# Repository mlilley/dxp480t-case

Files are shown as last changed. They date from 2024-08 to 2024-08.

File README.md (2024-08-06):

# DXP480T Custom Case

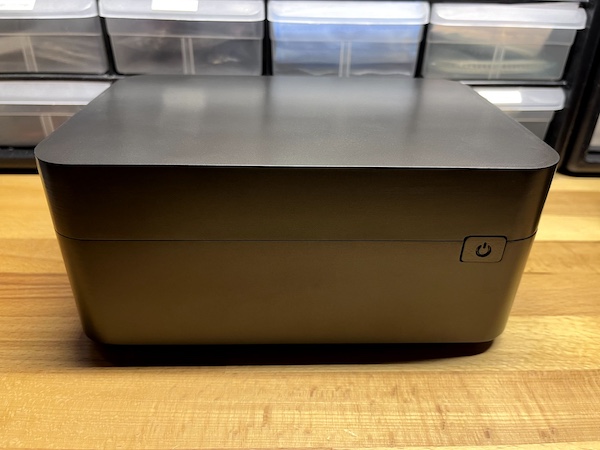
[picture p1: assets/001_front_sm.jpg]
Front


For more pictures, see: https://photos.app.goo.gl/Rahk7zdu8heuZMXZ9

## Printing & Assembly

Recommend printing case parts in ASA (to resist the hardware's high temps).  PLA or PETG should be avoided and will melt and/or distort.

To assemble ASA parts, prepare a mix of acetone and ASA scraps to make a glue.

You will also need:
* 20 x 5x2mm neodynium magnets (for the fan cover)
* 8 x M3 brass inserts (for the case halves and fan mount)
* 4 x 25mm M3 bolts (for case halves)
* 4 x 8mm M3 bolts (for fan)
* 1 x Noctua 120x25mm PWM fan (or compatible alternative)
* 1 x Noctua NA-FC1 PWM fan controller (or compatible alternative)
* 2 x 120x120mm pvc fan grille (or suitable alternative)

## NVME Mounting Bracket

To secure the NVME drives, see this repo for a 3d printable mounting bracket:
[dxp480t-nvme-bracket](https://github.com/mlilley/dxp480t-nvme-bracket)

## Fan Power

12V and ground for the 120mm fan can be obtained from the motherboard's pogo pin pads that originally connected to the factory case's uderside fans.

## Painting

To paint, I recommend spraying with a suitable primer before top coating with your chosen top coat.  I used [Mr. Finishing Surfacer 1500 Black](https://www.mr-hobby.com/en/product2/category_33/256.html) to prime, then [Gun Metal](https://www.splash-paints.com/product-page/gunmetal) from [Barbatos Rex' Mecha Empire range](https://www.splash-paints.com/barbatosrex) of anodized-look lacquers from Splash Paints.

I used an airbrush with a 0.8mm needle to get reasonable coverage over the large case parts.

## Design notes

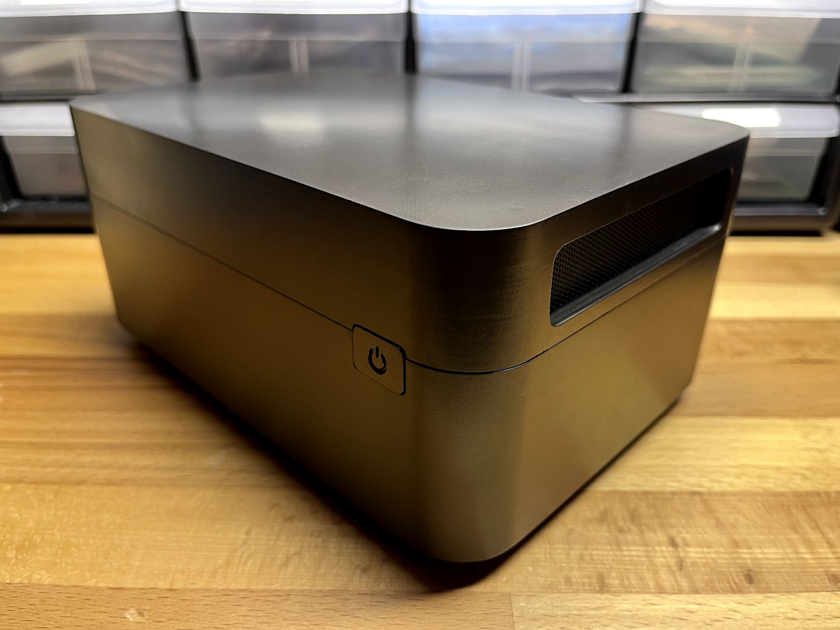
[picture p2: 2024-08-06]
assets/003_frontcorner.jpg

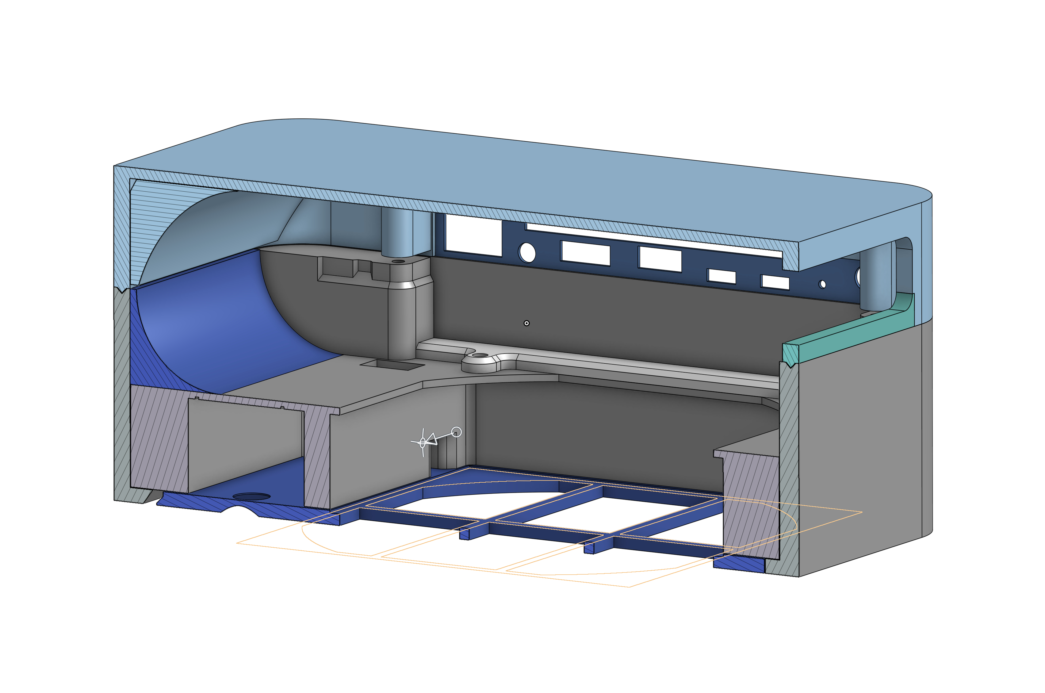
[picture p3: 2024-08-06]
assets/010_cad2.png

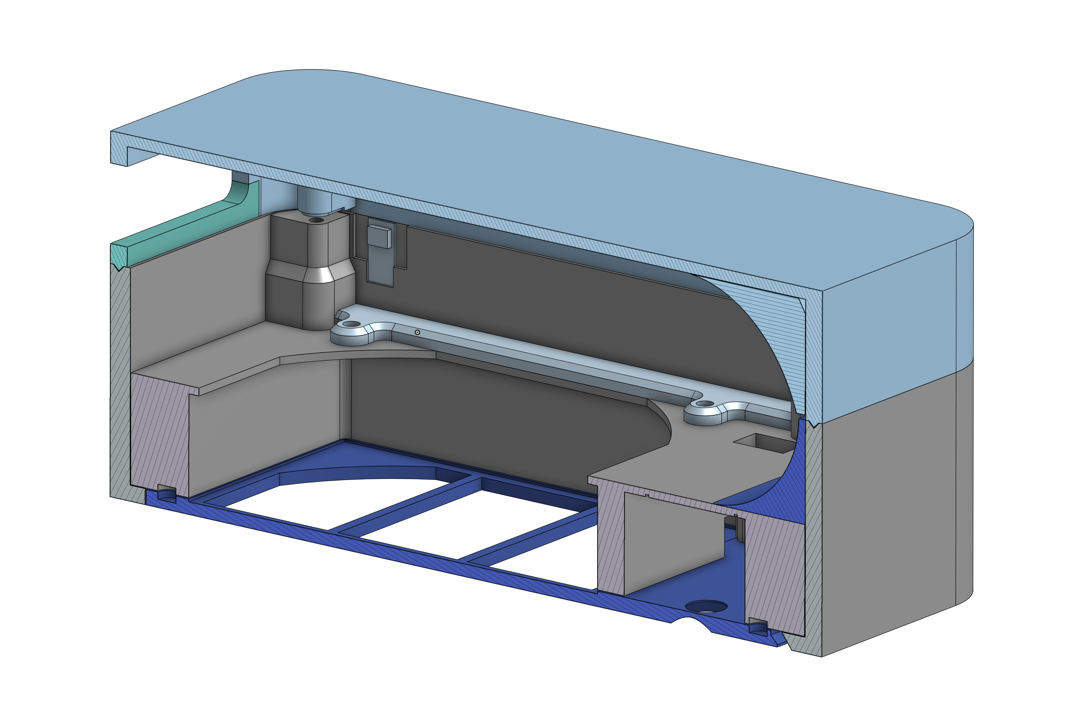
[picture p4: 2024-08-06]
assets/011_cad3.png

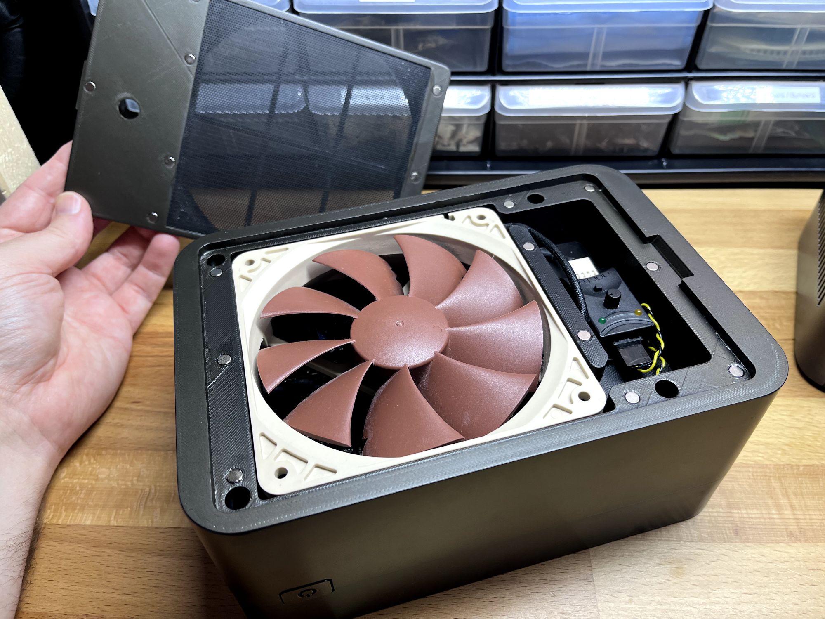
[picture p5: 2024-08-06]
assets/007_undersideopen.jpg

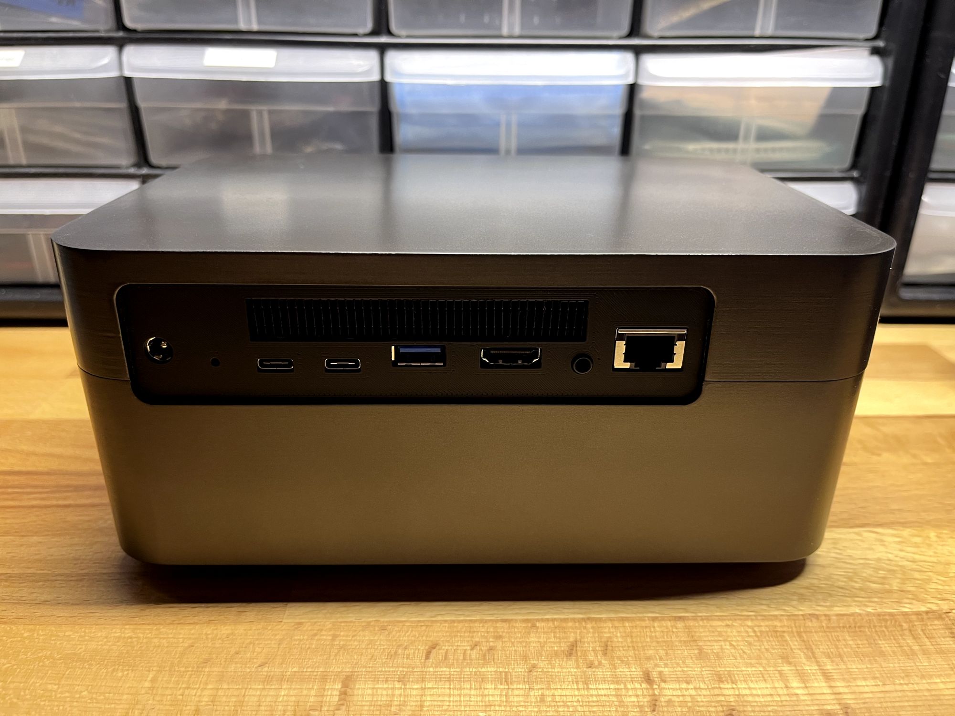
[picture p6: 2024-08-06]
assets/002_back.jpg

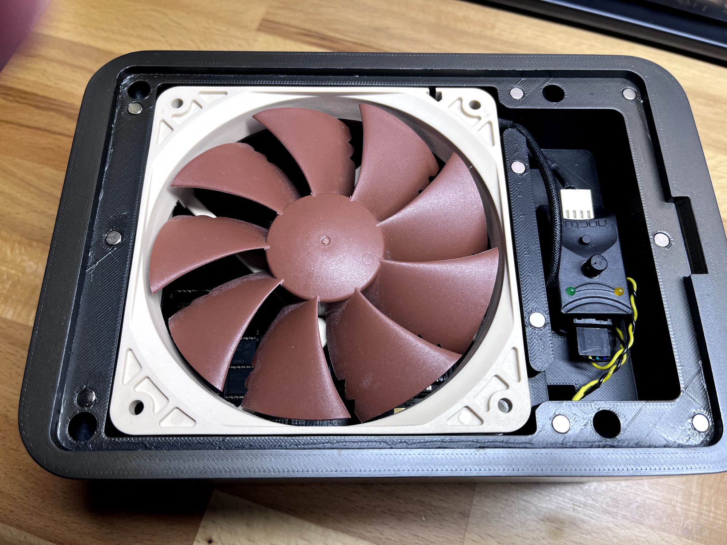
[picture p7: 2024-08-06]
assets/008_undersideopen2.jpg

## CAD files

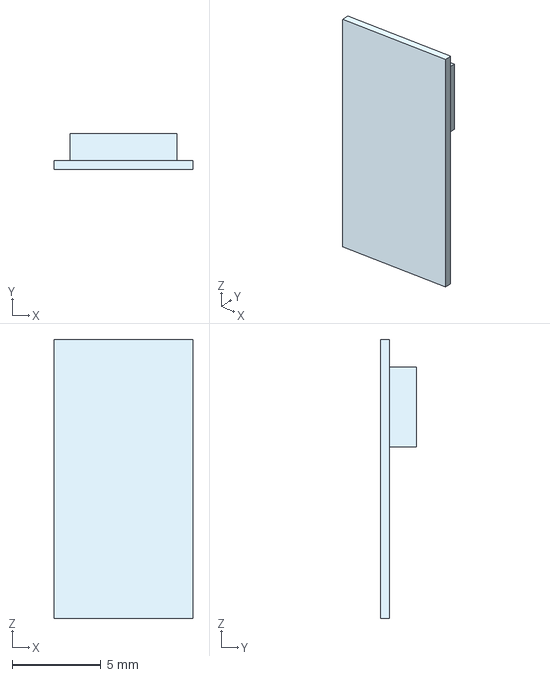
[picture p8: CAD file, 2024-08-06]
cad/Case - button back.step
7.80 x 2.00 x 15.7 mm

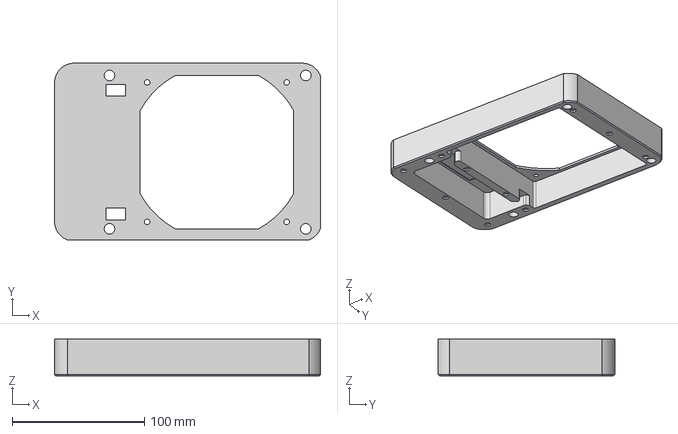
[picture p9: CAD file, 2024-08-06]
cad/Case - bottom insert.step
201.2 x 133.7 x 27.9 mm

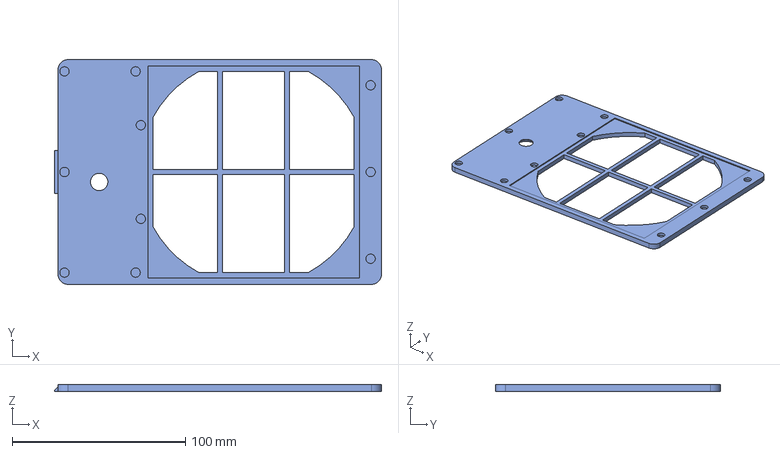
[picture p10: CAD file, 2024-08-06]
cad/Case - fan cover.step
188.5 x 129.5 x 3.84 mm

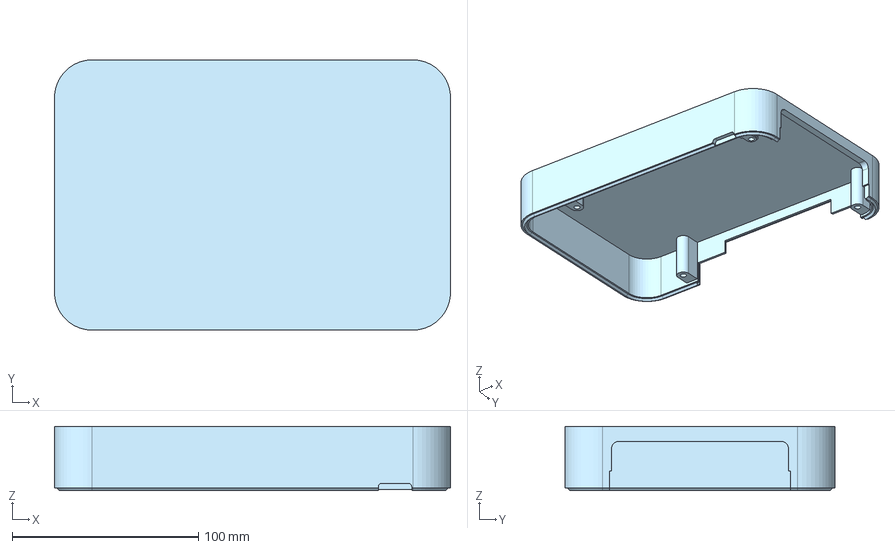
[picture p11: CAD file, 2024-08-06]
cad/Case - top.step
212.5 x 145.0 x 34.4 mm

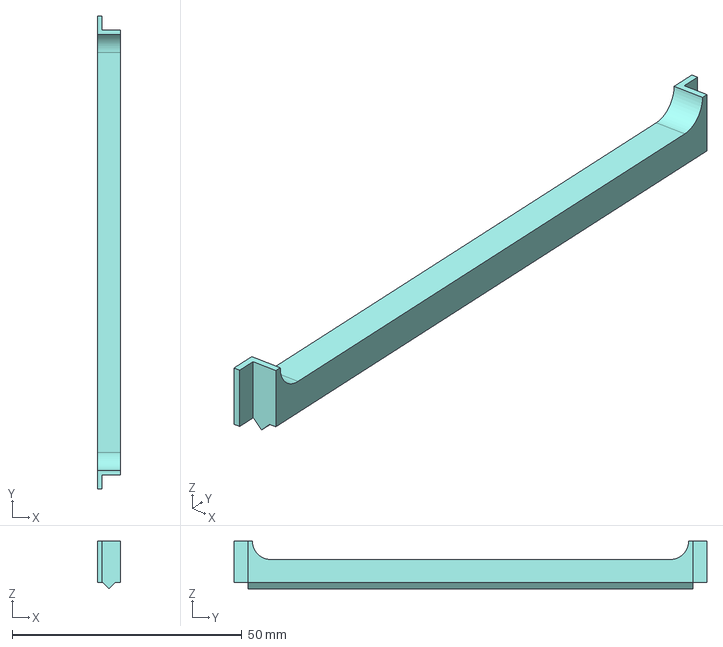
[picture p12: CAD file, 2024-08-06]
cad/Case - top side bracket.step
5.00 x 103.0 x 10.4 mm

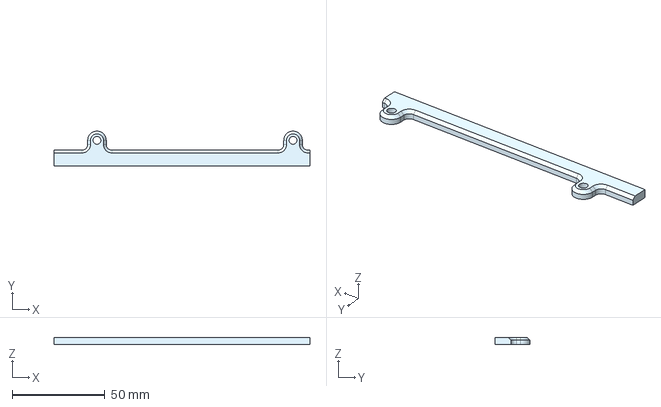
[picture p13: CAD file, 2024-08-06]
cad/Case - fan shim 2.step
137.8 x 18.8 x 4.00 mm

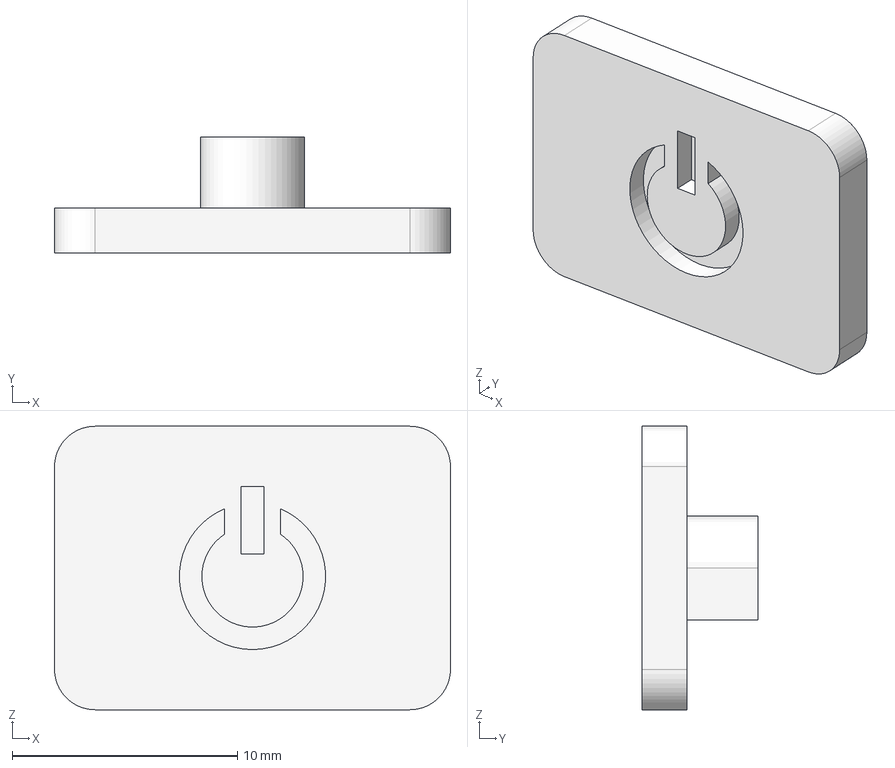
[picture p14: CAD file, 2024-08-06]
cad/Case - button face.step
17.6 x 5.16 x 12.6 mm

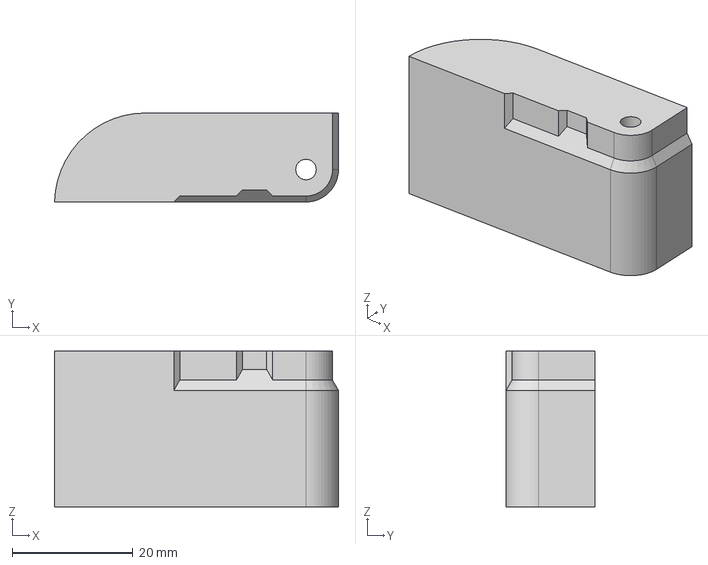
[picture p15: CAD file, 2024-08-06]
cad/Case - standoff 1.step
47.0 x 14.7 x 25.8 mm

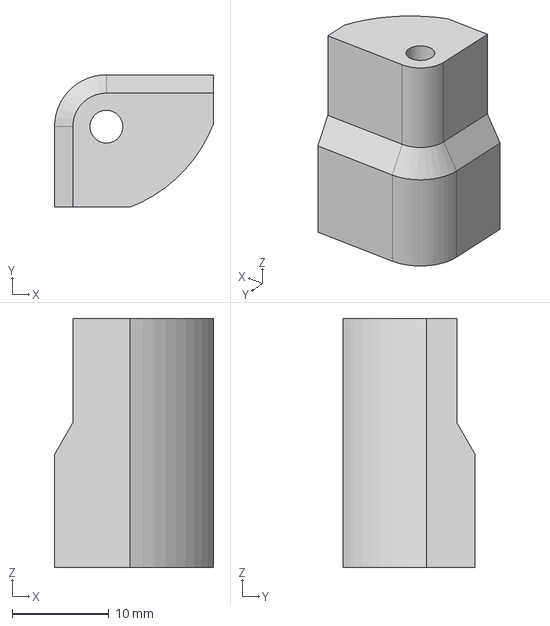
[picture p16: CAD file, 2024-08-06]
cad/Case - standoff 4.step
16.5 x 13.7 x 25.8 mm

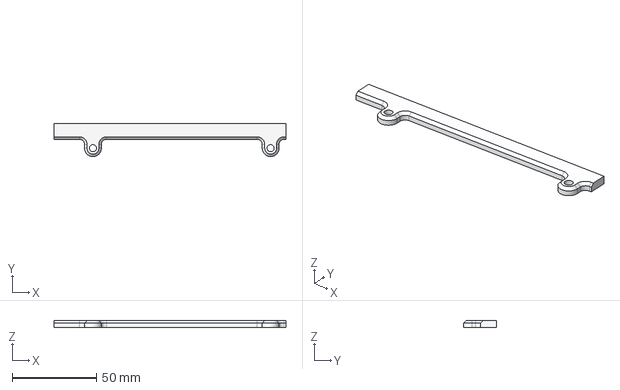
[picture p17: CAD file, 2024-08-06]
cad/Case - fan shim 1.step
137.8 x 19.8 x 4.00 mm

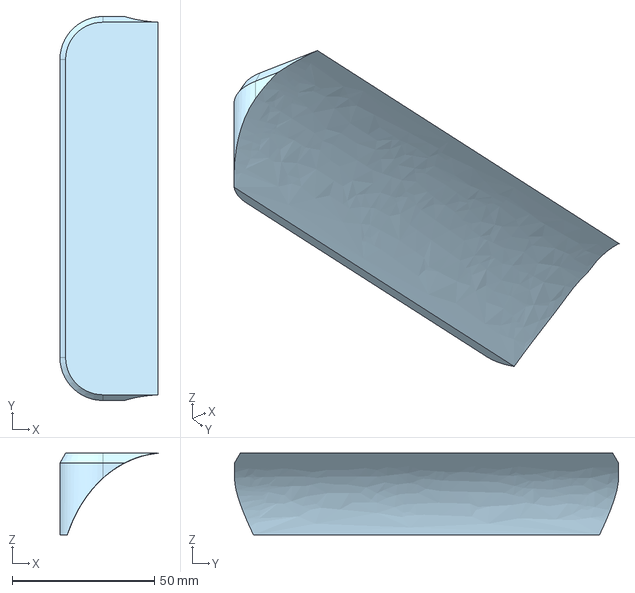
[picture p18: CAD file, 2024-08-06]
cad/Case - top air guide.step
34.5 x 134.8 x 28.7 mm

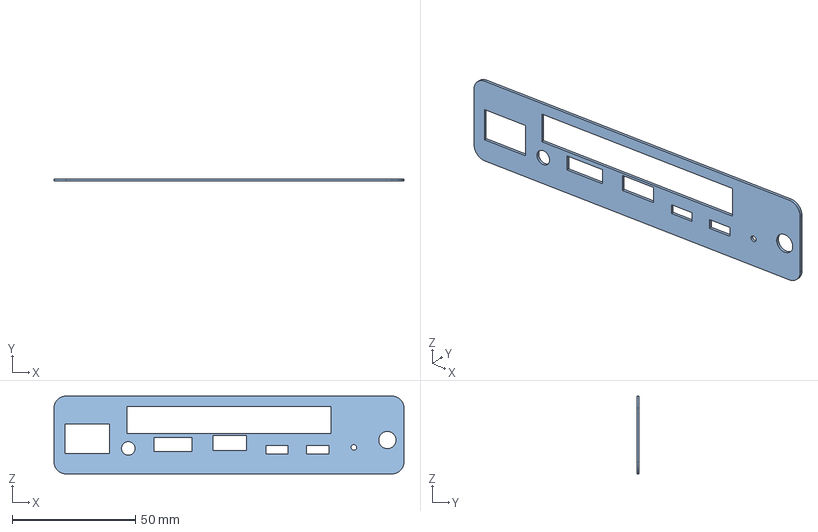
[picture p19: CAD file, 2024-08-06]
cad/Case - rear io.step
142.2 x 1.00 x 31.6 mm

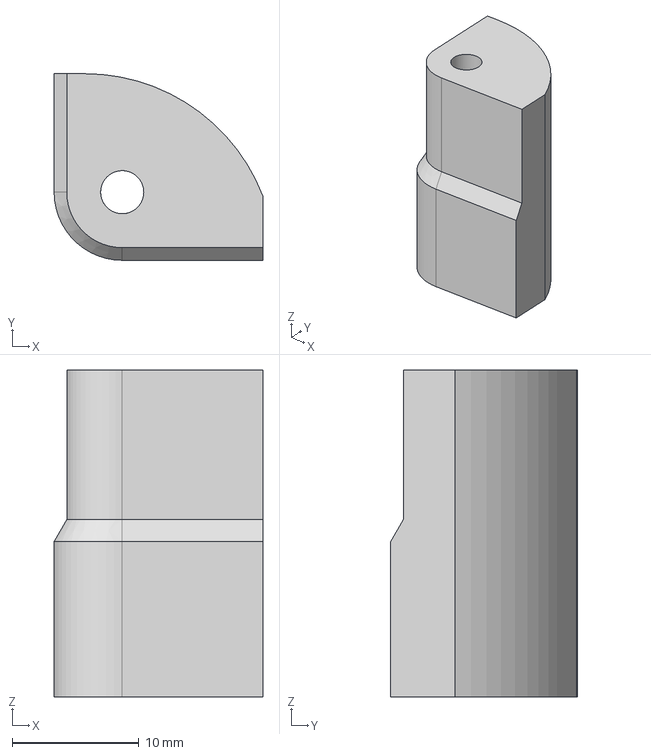
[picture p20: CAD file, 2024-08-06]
cad/Case - standoff 3.step
16.5 x 14.7 x 25.8 mm

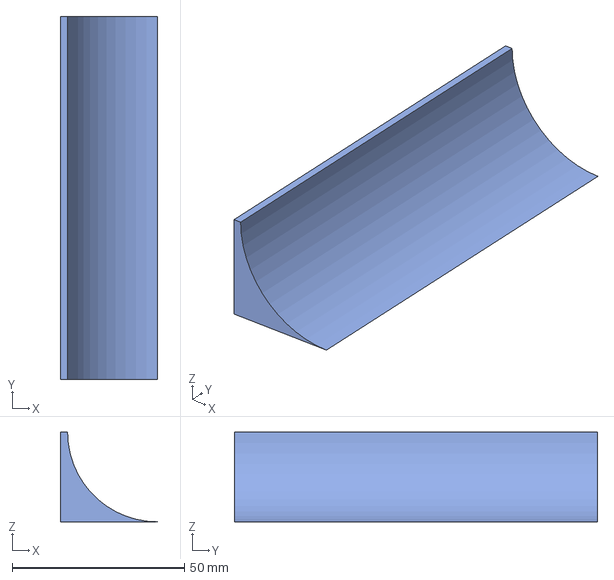
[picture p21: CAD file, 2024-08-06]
cad/Case - bottom air guide.step
28.0 x 105.2 x 26.0 mm

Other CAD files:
cad/Case - bottom.step
cad/Case - standoff 2.step
